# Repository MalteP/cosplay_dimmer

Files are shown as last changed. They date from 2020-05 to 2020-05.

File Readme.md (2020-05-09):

# Cosplay dimmer

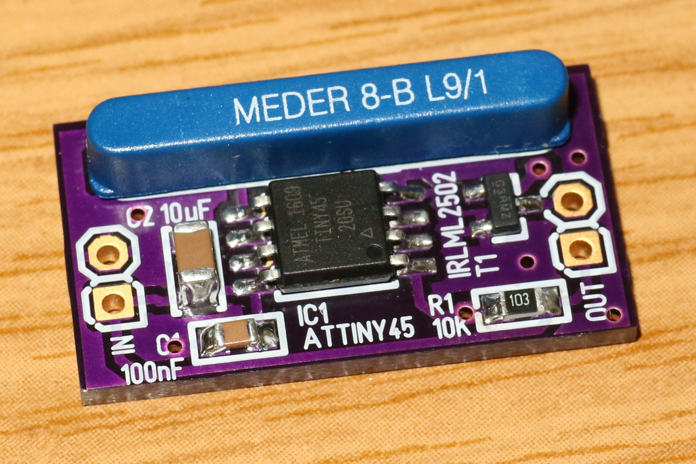
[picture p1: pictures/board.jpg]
Picture: Cosplay dimmer circuit board


## Project overview

Simple single channel PWM brightness control I made for a friend's cosplay. Uses a reed switch so it can be hidden behind foam parts, switching through different brightness levels is done with a magnet. Alternatively a regular tactile switch may be used. When the LED is completely switched off, a low power standby (~20µA) is implemented, making it ideal for battery powered applications. As power source either 2-3 1,5V batteries or a 5V power bank are possible.

## Schematic

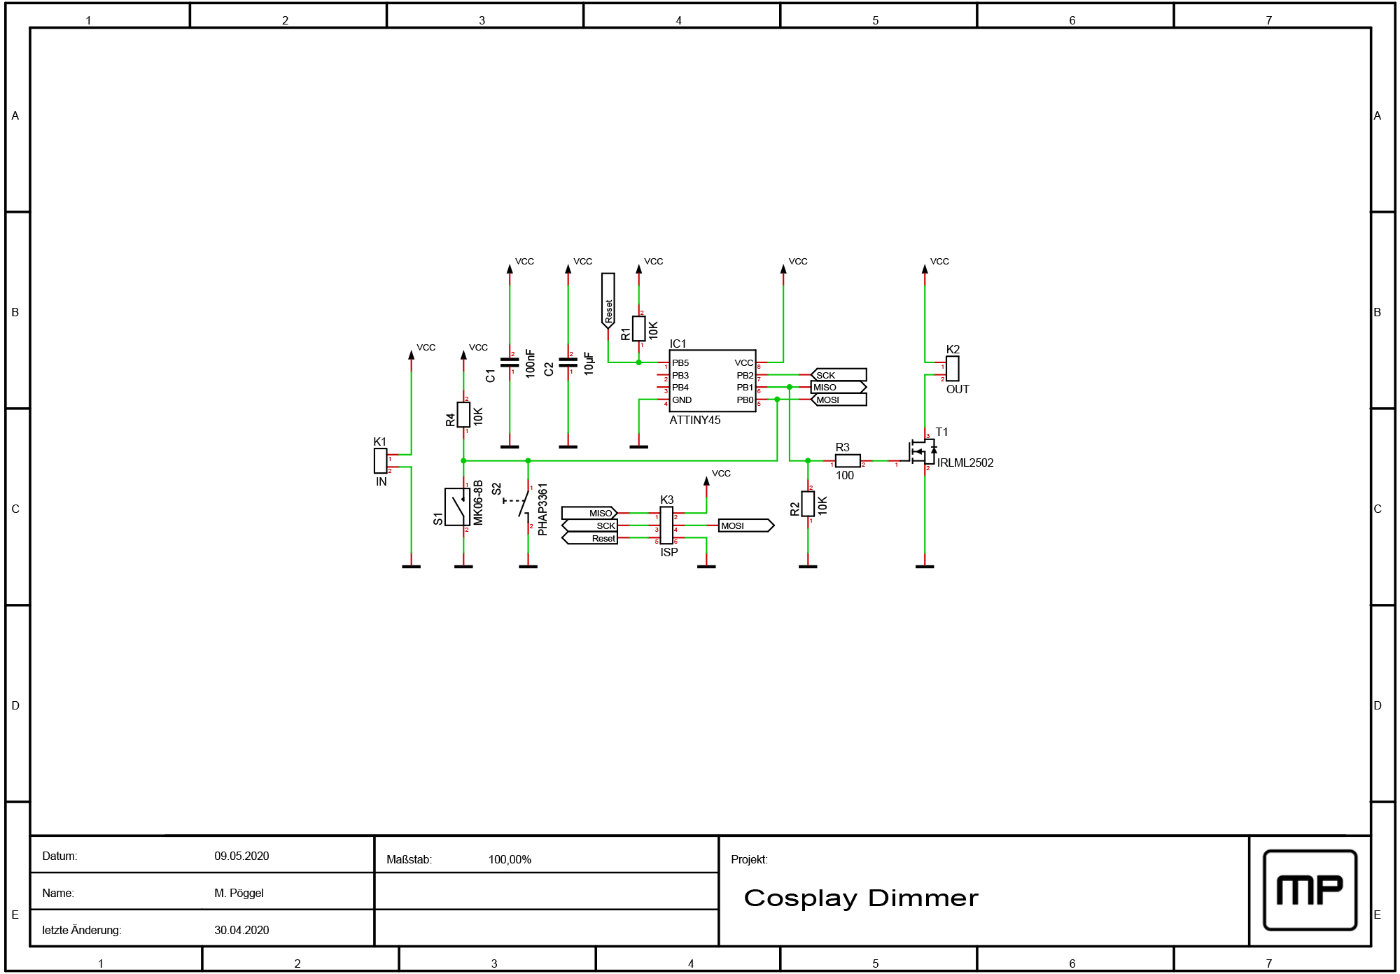
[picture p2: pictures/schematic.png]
Schematic


There are just a few components around the ATTiny45 microcontroller. The capacitors C1 and C2 stabilize the power supply, R1 and R4 are the pull up resistors for the reset signal and switch input, and the MOSFET T1 is used for driving the LED output.

## Circuit board

The double sided circuit board is designed using Target 3001 software, you'll also find the Gerber fabrication files in this repository. Just upload them to a PCB manufacturer of your choice, e.g. [Aisler](https://aisler.net/p/JEISYEOM), [OSHPark](https://oshpark.com/shared_projects/XIAtSLBW) or [Elecrow](https://www.elecrow.com/pcb-manufacturing.html).

## Firmware

For simplicity this project uses the PlatformIO build system. After installing it, just run the commands described below.

You might need to change platformio.ini to your programmer used. The circuit board has a 6 pin AVR ISP connector on the back side. I'd recommend soldering wires to those pads during the programming progress.

Compile the code:
```
platformio run
```

Write fusebits of the AVR microcontroller (only needs to be done once):
```
platformio run -t fuses
```

Flash firmware:
```
platformio run -t upload
```

## Customizing

If you like to change or add brightness levels, just modify the pwm_values[] array in the code, then compile and flash it again.

## License

The whole project is released under the terms of [GNU GPL v3](http://www.gnu.org/licenses/gpl-3.0.en.html).

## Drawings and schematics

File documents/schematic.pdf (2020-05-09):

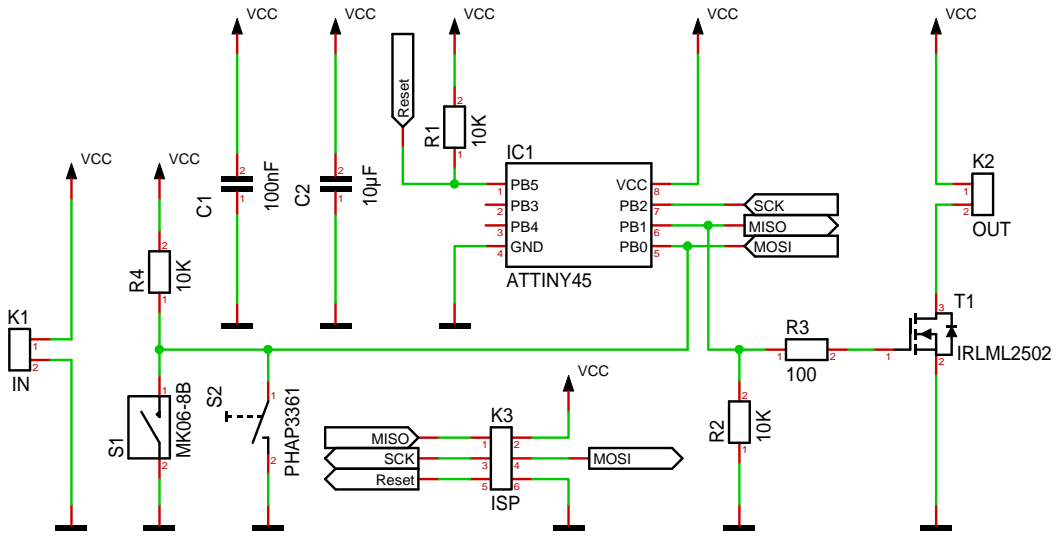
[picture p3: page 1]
PHAP3361; VCC; MOSI; Reset; SCK; MISO; OUT; MISO MOSI; ISP; IRLML2502; GND; ATTINY45

Datum: 09.05.2020 | Maßstab: 100,00% | Projekt: Cosplay Dimmer
M. Pöggel Name:

letzte Änderung: 30.04.2020

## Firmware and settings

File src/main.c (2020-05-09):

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
#include <avr/io.h>
#include <avr/interrupt.h>
#include <avr/sleep.h>
#include <util/delay.h>
#include "main.h"

int main( void )
 {
  // Init ports
  DDRB &= ~(1<<PB0);	// Switch input
  PORTB |= (1<<PB0);	// Enable internal pullup
  DDRB |= (1<<PB1);		// LED output (OC0B)

  // Setup timer
  TCCR0A |= (1<<COM0B1) | (1<<WGM00);	// Clear OC0B on Compare Match, PWM Phase Correct
  TCCR0B |= (1<<CS00);					// Clk/1
  OCR0B = 0;

  // Brigntness values
  int pwm_value = 0;
  const int pwm_values[] = {255, 128, 64, 32, 0};

  // Main loop
  while(1)
   {
    OCR0B = pwm_values[pwm_value];
    // Deep sleep on PWM value 0 and button not pressed
    sleep(pwm_values[pwm_value]==0&&!keystatus());
    // Check switch
    if(keydown())
     {
      // Loop through PWM value array
      if(++pwm_value>=(sizeof(pwm_values)/sizeof(pwm_values[0])))
       {
        pwm_value=0;
       }
     }
   }
 }

// Read key, negative logic
int keystatus( void )
 {
  return !(PINB & (1<<PB0));
 }

// Function to check if button / reed switch is pressed
int keydown( void )
 {
  int state = keystatus();
  static int debounce = 0;			// Counter for key debouncing
  if(debounce==0)
   {
    if(state) // Key down
     {
      debounce = 255; // Set debouncing time
      return 1;
     }
   } else {
    if(!state) // Key up
     {
      _delay_us(500);
      --debounce;
     }
   }
  return 0;
 }

// If LED is switched off, put AVR into deep sleep to save power (after some delay)
// Status flag must be set to 1 for given time bevor sleep mode is entered
void sleep( int status )
 {
  static int delay = 0;

  // Sleep mode delayed by 128ms, else interrupt might trigger immediately
  if(status==0)
   {
    delay = 255;
    return;
   } 
  if(delay>0)
   {
    _delay_us(500);
    --delay;
    return;
   }

  // Enable port change interrupt on PCINT0 (PB0)
  GIMSK |= (1<<PCIE);
  PCMSK |= (1<<PCINT0);

  // Enable global interrupts and go to sleep
  sei();
  set_sleep_mode(SLEEP_MODE_PWR_DOWN);
  sleep_mode();
  cli();

  // Disable PCINT
  GIMSK &= ~(1<<PCIE);
 }

// We'll wake up after deep sleep mode in this ISR
ISR(PCINT0_vect)
 {
 }

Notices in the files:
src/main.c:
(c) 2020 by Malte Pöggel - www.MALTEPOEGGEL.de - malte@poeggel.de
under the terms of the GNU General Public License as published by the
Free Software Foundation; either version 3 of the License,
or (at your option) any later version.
